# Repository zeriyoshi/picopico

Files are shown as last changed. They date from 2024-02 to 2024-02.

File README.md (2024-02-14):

# picopico EVT (Engineering Validation Test)

Validation and production test of `zeriyoshi/picoletta` and `zeriyoshi/xtrapico`.

## Specs

- Two `RP2040` implementations
    - BIG: Based on [`RetroScaler/RP2040-PICO-BOOT`](https://github.com/RetroScaler/RP2040-PICO-BOOT)
        - For main keyboard controller
        - Better and Rich implementation, not optimized usecase.
    - little: Based on [`zeriyoshi/xtrapico`](https://github.com/zeriyoshi/xtrapico)
        - For Raspberry Pi Pico compatible module
        - Simple and Flexible implementation, but unsure if it works.
        - xtrapico based on [`Breadstick-Innovations/22008-RP2040-Dev-Board`](https://github.com/Breadstick-Innovations/22008-RP2040-Dev-Board)
- `WS2812B-V5` and `SK6182MINI` testing environments
    - `RP2040` -> `WS2812B-V5` -> `SK6182MINI` Voltage conversion
    - `RP2040` -> MOSFET -> `SK6182MINI` Voltage conversion
    - Direct drive `SK6182MINI` on 3.3V
- Focus on manufactualing by [JLCPCB](https://jlcpcb.com/)

## Requirements

- KiCad 7
    - [`Bouni/kicad-jlcpcb-tools`](https://github.com/Bouni/kicad-jlcpcb-tools)
- Python 3
- Java Runtime Environment (for [`freerouting/freerouting`](https://github.com/freerouting/freerouting))

```bash
$ git clone --recursive "https://github.com/zeriyoshi/picopico" "picopico"
$ cd "picopico"
$ pip install -r "requirements.txt"
```

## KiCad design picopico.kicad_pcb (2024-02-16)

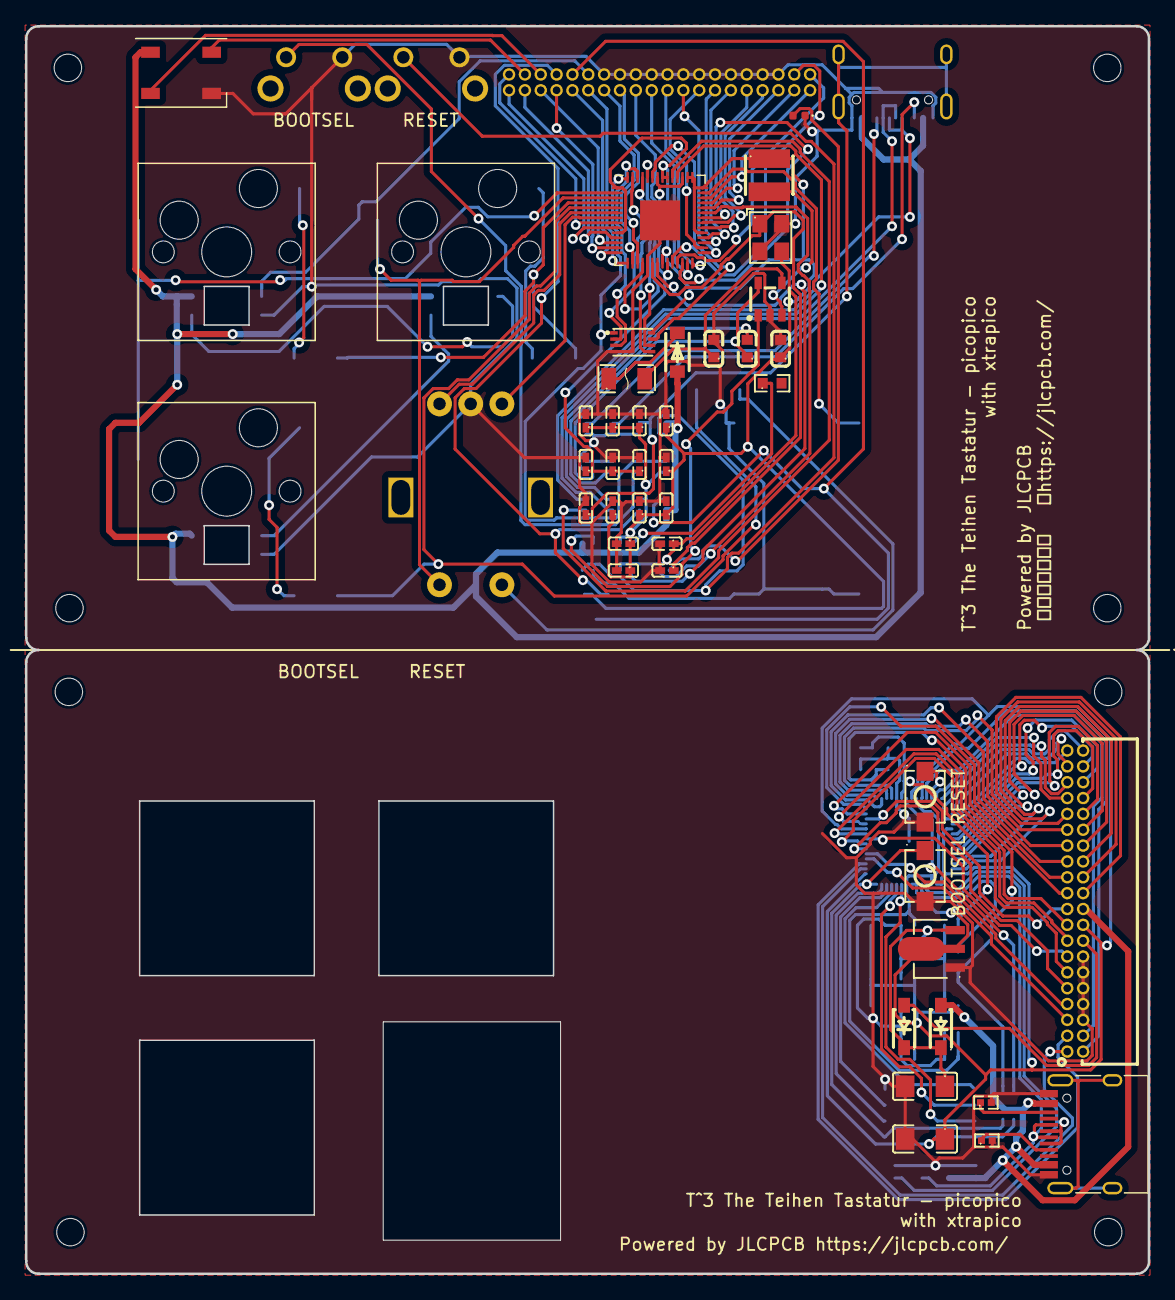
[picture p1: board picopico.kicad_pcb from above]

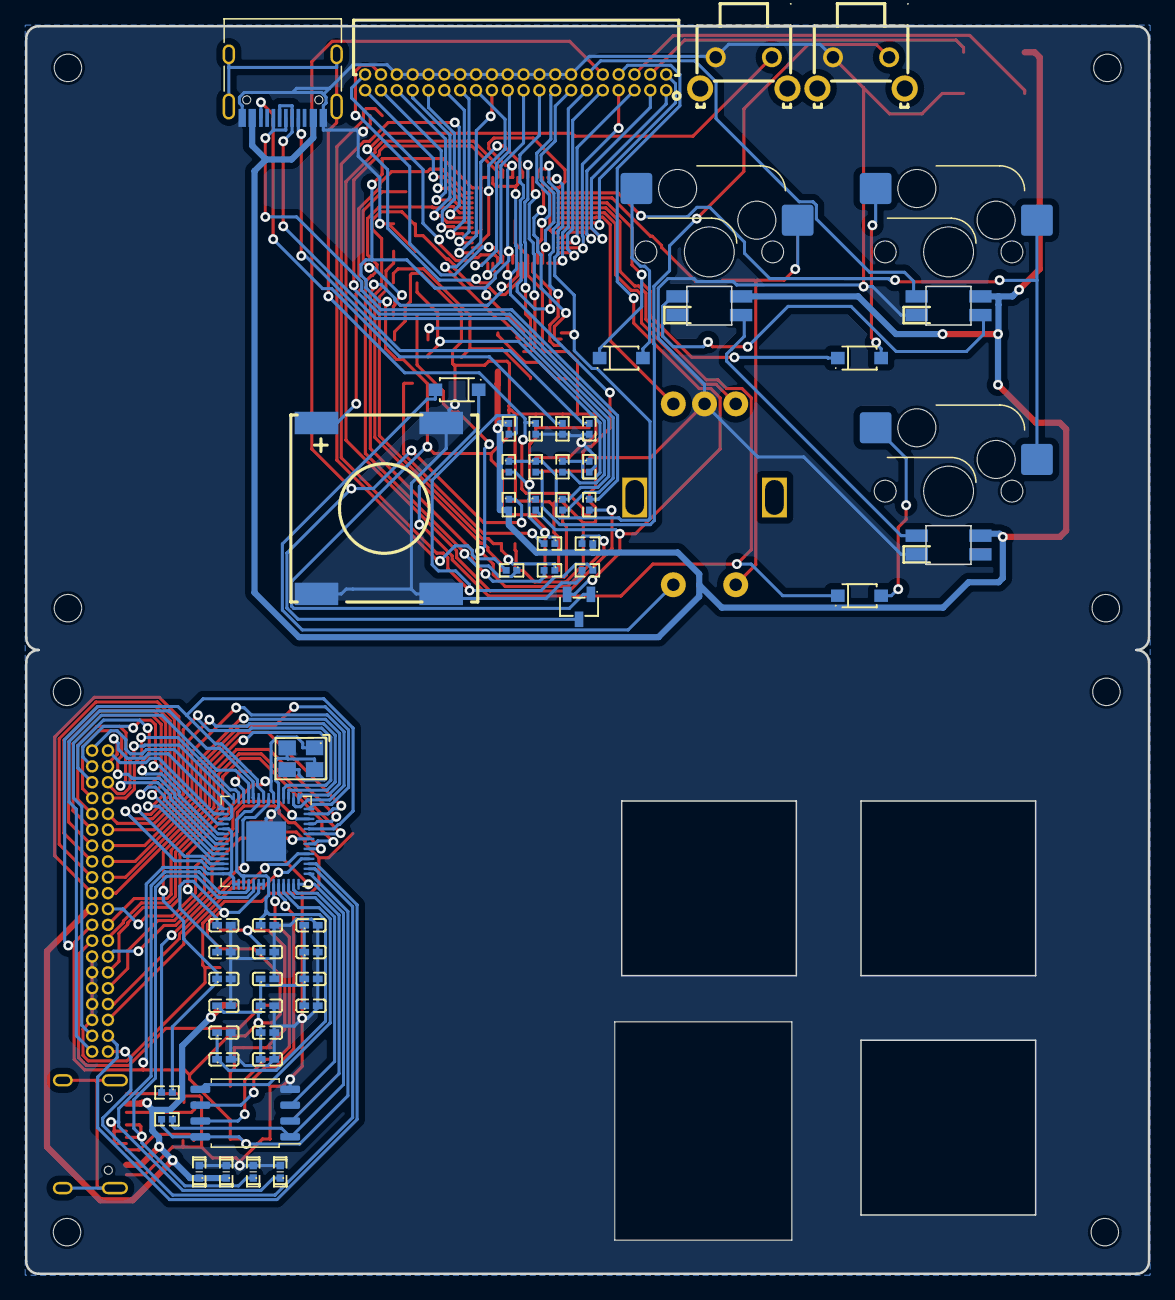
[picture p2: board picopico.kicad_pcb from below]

Board: 2 copper layers, 90.0 x 100.0 mm, 113 parts (55 on the bottom side), 124 nets.

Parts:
C1, C5, C6, C11, C12, C14, C15, C16, C17, C18, C19: CL05B104KO5NNNC; C0402
C2, C4: CL10A106KP8NNNC; C0603
C3: CL10C220JB8NNNC; C0603
C7: CL05A106MQ5NUNC; C0402
C8, C9: 0402CG220J500NT; C0402
C10, C13: CL05A105KA5NQNC; C0402
D1: WS2812B; LED_WS2812B_PLCC4_5.0x5.0mm_P3.2mm
D2: LED; LED_0402_1005Metric
D3, D4, D5, D6: 0402ESDA-05N; D0402-BI
F1: nSMD050-24V; F1206
FLASH1: W25Q16JVUXIQ; USON-8_L3.0-W2.0-P0.50-BL-EP
G2, G2#2: LOGO; zeriparrot
H1, H2, H3, H4, H5, H6, H7, H8: MountingHole; MountingHole_2.2mm_M2
H9, H10, H11: Switch_Hole
H12: RotaryEncoder_EC11-Hole
J1, J2: USB_C_Receptacle_USB2.0_14P; USB_C_Receptacle_HRO_TYPE-C-31-M-12
L1: SWPA3015S2R2NT; IND-SMD_L3.0-W3.0
R1, R2, R19, R20: 0402WGF5101TCE; R0402
R3: 0402WGF220JTCE; R0402
R4: 0402WGF5601TCE; R0402
R5, R10, R12, R16, R17: 0402WGF1002TCE; R0402
R6: 0402WGF1003TCE; R0402
R7: 0402WGF1503TCE; R0402
R8: 0402WGF6803TCE; R0402
R9, R11: 0402WGF1001TCE; R0402
R13: 0603WAF2001T5E; R0603
R14, R15: RC0402FR-0727RL; R0402
R18: 0402WGF4701TCE; R0402
SW1, SW2, SW3: SW_PUSH; SW_Hotswap_Kailh_MX_1.00u
SW4: RotaryEncoder_EC11-Switch
SW5, SW6: TSA343G00-250J2; SW-SMD_L4.0-W2.9-LS5.0
SW_BOOTSEL1: 1-1825027-7; SW-TH_KH-6X6X4.3H-ZJ
SW_RESET1: 1-1825027-7; SW-TH_KH-6X6X4.3H-ZJ
U1: 1N4002W; SOD-123F_L2.8-W1.8-LS3.7-RD
U2: TD6810; SOT-23-5_L3.0-W1.7-P0.95-LS2.8-BR
U3: RP2040; QFN-56-1EP_7x7mm_P0.4mm_EP3.2x3.2mm
U4, U14: X1321FR-2X20-C43D24; CONN-TH_40P_X1321FR-2X20-C43D24
U5, U6, U7, U8: 1N4148W_C81598; SOD-123F_L2.7-W1.6-LS3.8-RD
U9: BSS138; SOT-23-3_L2.9-W1.3-P1.90-LS2.4-BR
U10, U11, U12: RGBLED_SK6812MINI-E
U13: FS-1540; BUZ-SMD_5P-L15.0-W15.0-P13.7-BL
X1: X322512MSB4SI; OSC-SMD_4P-L3.2-W2.5-BL
XTRAPI_C1, XTRAPI_C3: 0402CG300J500NT; C0402
XTRAPI_C2, XTRAPI_C5, XTRAPI_C6, XTRAPI_C7, XTRAPI_C8, XTRAPI_C9, XTRAPI_C10, XTRAPI_C11, XTRAPI_C12, XTRAPI_C13, XTRAPI_C15, XTRAPI_C16, XTRAPI_C17, XTRAPI_C18: CL05A106MQ5NUNC; C0402
XTRAPI_C4, XTRAPI_C14: CL31A107MQHNNNE; C1206
XTRAPI_R2: 0402WGF1002TCE; R0402
XTRAPI_R4: 0402WGF1001TCE; R0402
XTRAPI_U2: W25Q128JVS; SOIC-8_5.23x5.23mm_P1.27mm
XTRAPI_U3: RP2040; QFN-56-1EP_7x7mm_P0.4mm_EP3.2x3.2mm
XTRAPI_U4: AZ1117R-3_3TRE1; SOT-89-3_L4.5-W2.5-P1.50-LS4.2-BR
XTRAPI_U6, XTRAPI_U7: B5819W_C8598; SOD-123_L2.7-W1.6-LS3.7-RD-1
XTRAPI_X1: X322512MSB4SI; OSC-SMD_4P-L3.2-W2.5-BL

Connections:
+1V1: C10.1, C11.1, C12.1, U3.23 (DVDD), U3.45 (VREG_VOUT), U3.50 (DVDD)
+3V3: C4.1, C5.1, C6.1, C7.1, C13.1, C14.1, C15.1, C16.1, C17.1, C18.1, C19.1, FLASH1.8 (VCC), L1.2, R10.2, R12.1, R16.1, U3.1 (IOVDD), U3.10 (IOVDD), U3.22 (IOVDD), U3.33 (IOVDD), U3.42 (IOVDD), U3.43 (ADC_AVDD), U3.44 (VREG_IN), U3.48 (USB_VDD), U3.49 (IOVDD), U9.1 (G)
/COL0: SW1.1, SW3.1, U3.2 (GPIO0)
/COL1: SW2.1, SW4.S2, U3.3 (GPIO1)
/GPIO24: R4.2, R5.1, U3.36 (GPIO24)
/GPIO25: R18.1, U3.37 (GPIO25)
/MOSFETIN: R16.2, U4.8, U9.2 (S)
/MOSFETOUT: R17.1, U4.10, U9.3 (D)
/RGBEXT: U3.8 (GPIO6), U4.2
/RGBREV: U4.12, U10.4 (DIN)
/ROT0IN: SW4.B, U3.6 (GPIO4)
/ROT0OUT: SW4.A, U3.7 (GPIO5)
/ROW0: U3.4 (GPIO2), U5.1 (K), U6.1 (K)
/ROW1: U3.5 (GPIO3), U7.1 (K), U8.1 (K)
/SWCLK: U3.24 (SWCLK), U4.38
/SWD: U3.25 (SWD), U4.40
/VSYS: F1.1, U1.1 (C)
/WSIN: D1.4 (DIN), U4.4
/WSOUT: D1.2 (DOUT), U4.6
/XP_+3V3: U14.18, XTRAPI_C2.1, XTRAPI_C4.1, XTRAPI_C5.1, XTRAPI_C10.1, XTRAPI_C11.1, XTRAPI_C12.1, XTRAPI_C13.1, XTRAPI_C15.1, XTRAPI_C16.1, XTRAPI_C17.1, XTRAPI_C18.1, XTRAPI_R2.2, XTRAPI_U2.8 (VCC), XTRAPI_U3.1 (IOVDD), XTRAPI_U3.10 (IOVDD), XTRAPI_U3.22 (IOVDD), XTRAPI_U3.33 (IOVDD), XTRAPI_U3.42 (IOVDD), XTRAPI_U3.43 (ADC_AVDD), XTRAPI_U3.44 (VREG_IN), XTRAPI_U3.48 (USB_VDD), XTRAPI_U3.49 (IOVDD), XTRAPI_U4.2 (OUTPUT)
/XP_BOOTSEL: SW6.1, XTRAPI_R2.1, XTRAPI_U2.1 (~CS), XTRAPI_U3.56 (QSPI_SS)
/XP_GPIO0: U14.1, XTRAPI_U3.2 (GPIO0)
/XP_GPIO1: U14.3, XTRAPI_U3.3 (GPIO1)
/XP_GPIO2: U14.5, XTRAPI_U3.4 (GPIO2)
/XP_GPIO3: U14.7, XTRAPI_U3.5 (GPIO3)
/XP_GPIO4: U14.9, XTRAPI_U3.6 (GPIO4)
/XP_GPIO5: U14.11, XTRAPI_U3.7 (GPIO5)
/XP_GPIO6: U14.13, XTRAPI_U3.8 (GPIO6)
/XP_GPIO7: U14.15, XTRAPI_U3.9 (GPIO7)
/XP_GPIO8: U14.17, XTRAPI_U3.11 (GPIO8)
/XP_GPIO9: U14.19, XTRAPI_U3.12 (GPIO9)
/XP_GPIO10: U14.21, XTRAPI_U3.13 (GPIO10)
/XP_GPIO11: U14.23, XTRAPI_U3.14 (GPIO11)
/XP_GPIO12: U14.25, XTRAPI_U3.15 (GPIO12)
/XP_GPIO13: U14.27, XTRAPI_U3.16 (GPIO13)
/XP_GPIO14: U14.29, XTRAPI_U3.17 (GPIO14)
/XP_GPIO15: U14.31, XTRAPI_U3.18 (GPIO15)
/XP_GPIO16: U14.33, XTRAPI_U3.27 (GPIO16)
/XP_GPIO17: U14.35, XTRAPI_U3.28 (GPIO17)
/XP_GPIO18: U14.37, XTRAPI_U3.29 (GPIO18)
/XP_GPIO19: U14.39, XTRAPI_U3.30 (GPIO19)
/XP_GPIO20: U14.40, XTRAPI_U3.31 (GPIO20)
/XP_GPIO21: U14.38, XTRAPI_U3.32 (GPIO21)
/XP_GPIO22: U14.36, XTRAPI_U3.34 (GPIO22)
/XP_GPIO23: U14.34, XTRAPI_U3.35 (GPIO23)
/XP_GPIO24: U14.32, XTRAPI_U3.36 (GPIO24)
/XP_GPIO25: U14.30, XTRAPI_U3.37 (GPIO25)
/XP_GPIO26_ADC0: U14.28, XTRAPI_U3.38 (GPIO26_ADC0)
/XP_GPIO27_ADC1: U14.26, XTRAPI_U3.39 (GPIO27_ADC1)
/XP_GPIO28_ADC2: U14.24, XTRAPI_U3.40 (GPIO28_ADC2)
/XP_GPIO29_ADC3: U14.22, XTRAPI_U3.41 (GPIO29_ADC3)
/XP_RUN: SW5.1, XTRAPI_U3.26 (RUN)
/XP_SWCLK: U14.2, XTRAPI_U3.24 (SWCLK)
/XP_SWD: U14.4, XTRAPI_U3.25 (SWD)
/XP_USB_DN: D6.1, J2.A7 (D-), J2.B7 (D-), XTRAPI_U3.46 (USB_DM)
/XP_USB_DP: D5.1, J2.A6 (D+), J2.B6 (D+), XTRAPI_U3.47 (USB_DP)
/XP_VBUS: D3.1, D4.1, J2.A4 (VBUS), J2.A9 (VBUS), J2.B4 (VBUS), J2.B9 (VBUS), U14.20, XTRAPI_U7.2 (+)
/XP_VSYS: U14.16, XTRAPI_U6.2 (+)
GND: C1.2, C2.2, C4.2, C5.2, C6.2, C7.2, C8.2, C9.2, C10.2, C11.2, C12.2, C13.2, C14.2, C15.2, C16.2, C17.2, C18.2, C19.2, D1.3 (VSS), D2.1 (K), D3.2, D4.2, D5.2, D6.2, FLASH1.4 (GND), FLASH1.9 (EP), J1.A1 (GND), J1.A12 (GND), J1.B1 (GND), J1.B12 (GND), J2.A1 (GND), J2.A12 (GND), J2.B1 (GND), J2.B12 (GND), R1.2, R2.2, R3.2, R5.2, R7.2, R19.2, R20.2, SW4.C, SW5.2, SW6.2, SW_BOOTSEL1.2, SW_RESET1.2, U2.2 (GND), U3.19 (TESTEN), U3.57 (GND), U4.14, U4.16, U4.18, U4.20, U4.22, U4.24, U4.26, U4.28, U4.30, U4.32, U4.34, U4.36, U10.3 (GND), U11.3 (GND), U12.3 (GND), U13.2, U13.3, U13.4, U14.6, U14.8, U14.10, U14.12, U14.14, X1.2 (GND), X1.4 (GND), XTRAPI_C1.2, XTRAPI_C2.2, XTRAPI_C3.2, XTRAPI_C4.2, XTRAPI_C5.2, XTRAPI_C6.2, XTRAPI_C7.2, XTRAPI_C8.2, XTRAPI_C9.2, XTRAPI_C10.2, XTRAPI_C11.2, XTRAPI_C12.2, XTRAPI_C13.2, XTRAPI_C14.2, XTRAPI_C15.2, XTRAPI_C16.2, XTRAPI_C17.2, XTRAPI_C18.2, XTRAPI_U2.4 (GND), XTRAPI_U3.19 (TESTEN), XTRAPI_U3.57 (GND), XTRAPI_U4.1 (ADJ/GND), XTRAPI_X1.2 (GND), XTRAPI_X1.4 (GND)
unnamed: C3.2, R8.2
unnamed: D2.2 (A), R18.2
unnamed: FLASH1.6 (CLK), U3.52 (QSPI_SCLK)
unnamed: FLASH1.1 (CS#), R9.1, R10.1, U3.56 (QSPI_SS)
unnamed: FLASH1.5 (DI(IO0)), U3.53 (QSPI_SD0)
unnamed: FLASH1.2 (DO(IO1)), U3.55 (QSPI_SD1)
unnamed: FLASH1.7 (HOLD#orRESET#(IO3)), U3.51 (QSPI_SD3)
unnamed: FLASH1.3 (WP#(IO2)), U3.54 (QSPI_SD2)
unnamed: J1.A5 (CC1), R1.1
unnamed: J1.B5 (CC2), R2.1
unnamed: J1.A6 (D+), J1.B6 (D+), R14.1
unnamed: J1.A7 (D-), J1.B7 (D-), R15.1
unnamed: C1.1, J1.S1 (SHIELD), R3.1
unnamed: J2.A5 (CC1), R20.1
unnamed: J2.B5 (CC2), R19.1
unnamed: R9.2, SW_BOOTSEL1.1
unnamed: R12.2, R13.1
unnamed: R6.2, U2.1 (RUN)
unnamed: L1.1, U2.3 (SW)
unnamed: C3.1, R7.1, R8.1, U2.5 (VFB/VOUT)
unnamed: C2.1, F1.2, U2.4 (VIN)
unnamed: U3.9 (GPIO7), U4.1
unnamed: U3.11 (GPIO8), U4.3
unnamed: U3.12 (GPIO9), U4.5
unnamed: U3.13 (GPIO10), U4.7
unnamed: U3.14 (GPIO11), U4.9
unnamed: U3.15 (GPIO12), U4.11
unnamed: U3.16 (GPIO13), U4.13
unnamed: U3.17 (GPIO14), U4.15
unnamed: U3.18 (GPIO15), U4.17
unnamed: U3.27 (GPIO16), U4.19
unnamed: U3.28 (GPIO17), U4.21
unnamed: U3.29 (GPIO18), U4.23
unnamed: U3.30 (GPIO19), U4.25
unnamed: U3.31 (GPIO20), U4.27
unnamed: U3.32 (GPIO21), U4.29
unnamed: U3.34 (GPIO22), U4.31
unnamed: U3.35 (GPIO23), U4.33
unnamed: U3.38 (GPIO26_ADC0), U4.35
unnamed: U3.39 (GPIO27_ADC1), U4.37
unnamed: U3.40 (GPIO28_ADC2), U4.39
unnamed: SW_RESET1.1, U3.26 (RUN)
unnamed: R15.2, U3.46 (USB_DM)
unnamed: R14.2, U3.47 (USB_DP)
unnamed: C8.1, U3.20 (XIN), X1.1 (OSC1)
unnamed: R11.2, U3.21 (XOUT)
unnamed: SW1.2, U5.2 (A)
unnamed: SW2.2, U6.2 (A)
unnamed: SW3.2, U7.2 (A)
unnamed: SW4.S1, U8.2 (A)
unnamed: U10.2 (DOUT), U11.4 (DIN)
unnamed: U11.2 (DOUT), U12.4 (DIN)
unnamed: U3.41 (GPIO29_ADC3), U13.1 (+)
unnamed: C9.1, R11.1, X1.3 (OSC2)
unnamed: XTRAPI_U2.6 (CLK), XTRAPI_U3.52 (QSPI_SCLK)
unnamed: XTRAPI_U2.5 (DI(IO0)), XTRAPI_U3.53 (QSPI_SD0)
unnamed: XTRAPI_U2.2 (DO(IO1)), XTRAPI_U3.55 (QSPI_SD1)
unnamed: XTRAPI_U2.3 (IO2), XTRAPI_U3.54 (QSPI_SD2)
unnamed: XTRAPI_U2.7 (IO3), XTRAPI_U3.51 (QSPI_SD3)
unnamed: XTRAPI_C6.1, XTRAPI_C7.1, XTRAPI_C8.1, XTRAPI_U3.23 (DVDD), XTRAPI_U3.45 (VREG_VOUT), XTRAPI_U3.50 (DVDD)
unnamed: XTRAPI_C1.1, XTRAPI_U3.20 (XIN), XTRAPI_X1.1 (OSC1)
unnamed: XTRAPI_R4.2, XTRAPI_U3.21 (XOUT)
unnamed: XTRAPI_C9.1, XTRAPI_C14.1, XTRAPI_U4.3 (INPUT), XTRAPI_U6.1 (-), XTRAPI_U7.1 (-)
unnamed: XTRAPI_C3.1, XTRAPI_R4.1, XTRAPI_X1.3 (OSC2)
VBUS: D1.1 (VDD), J1.A4 (VBUS), J1.A9 (VBUS), J1.B4 (VBUS), J1.B9 (VBUS), R4.1, R6.1, R17.2, U1.2 (A), U10.1 (VDD), U11.1 (VDD), U12.1 (VDD)
